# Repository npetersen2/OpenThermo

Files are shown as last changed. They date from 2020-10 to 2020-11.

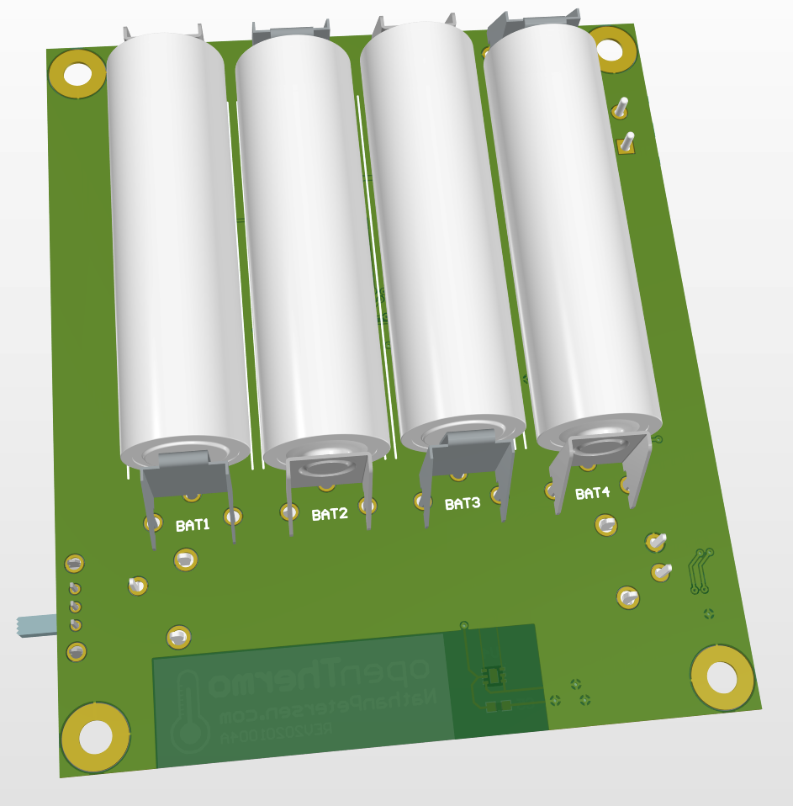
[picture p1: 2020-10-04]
hardware/REV20201004A/PCB_3D_bottom.png

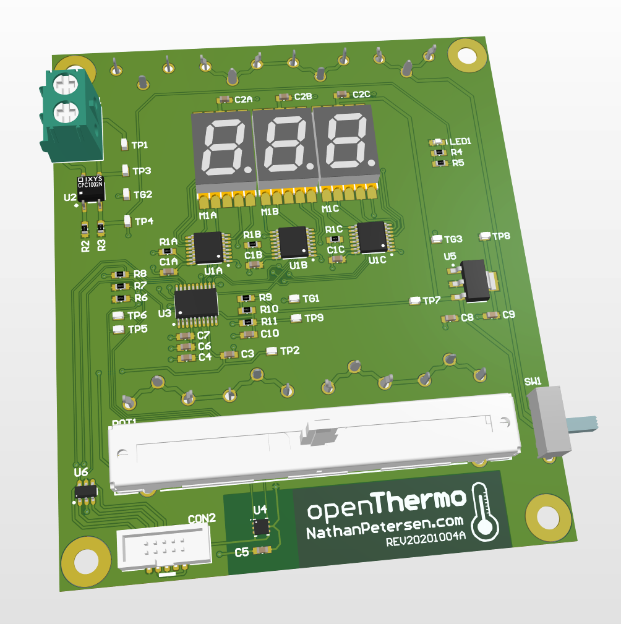
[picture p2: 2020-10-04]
hardware/REV20201004A/PCB_3D_top.png

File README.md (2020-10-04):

# openThermo

*Open-source thermostat for control of simple on/off furnaces.*

## About

This project was born after renting an old house with a crappy furnace controller. The crappy controller in the house used a timer to control when the heat was on; there was no closed-loop feedback to regulate temperature.

This project solves the issue by adding closed-loop temperature feedback.

## Contact

For questions or comments, please connect Nathan Petersen <nathan.petersen@wisc.edu>

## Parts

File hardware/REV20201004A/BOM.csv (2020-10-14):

Comment | Designator | Quantity | Qty 10 | Supplier Part Number 1
AA Holder | BAT1, BAT2, BAT3, BAT4 | 4 | 40 | 36-590-ND
AA Holder | BAT1, BAT2, BAT3, BAT4 | 4 | 40 | 36-596-ND
Capacitor | C1A, C1B, C1C, C2A, C2B, C2C, C4, C5, C6, C10 | 10 | 100 | 311-1343-1-ND
Capacitor | C3, C7, C8, C9 | 4 | 40 | 1276-1192-1-ND
ScrewTerminal_1x2 | CON1 | 1 | 10 | 277-1667-ND
20021521-00010D4LF | CON2 | 1 | 10 | 609-6533-ND
RED | LED1 | 1 | 10 | 160-1447-6-ND
VDMR10A0 | M1A, M1B, M1C | 3 | 30 | VDMR10A0CT-ND
PTA4543-2010CIB103 | POT1 | 1 | 10 | PTA4543-2010CIB103-ND
Resistor | R1A, R1B, R1C, R6, R7 | 5 | 50 | YAG1304CT-ND
Resistor | R2 | 1 | 10 | 311-470HRCT-ND
Resistor | R3, R8, R9, R10, R11 | 5 | 50 | 311-10.0KHRCT-ND
Resistor | R4, R5 | 2 | 20 | 311-1.00KHRCT-ND
EG1213 | SW1 | 1 | 10 | EG1906-ND
RCU-0C | TG1, TG2, TG3, TP1, TP2, TP3, TP4, TP5, TP6, TP7, TP8, TP9 | 12 | 120 | A106145CT-ND
STP08DP05TTR | U1A, U1B, U1C | 3 | 30 | 497-6029-1-ND
CPC1002NTR | U2 | 1 | 10 | CLA230CT-ND
STM32G030F6P6 | U3 | 1 | 10 | 497-STM32G030F6P6-ND
TMP117MAIDRVR | U4 | 1 | 10 | 296-51835-1-ND
AP2114H-3.3TRG1 | U5 | 1 | 10 | AP2114H-3.3TRG1DICT-ND
NUP4114HMR6T1G | U6 | 1 | 10 | NUP4114HMR6T1GOSCT-ND

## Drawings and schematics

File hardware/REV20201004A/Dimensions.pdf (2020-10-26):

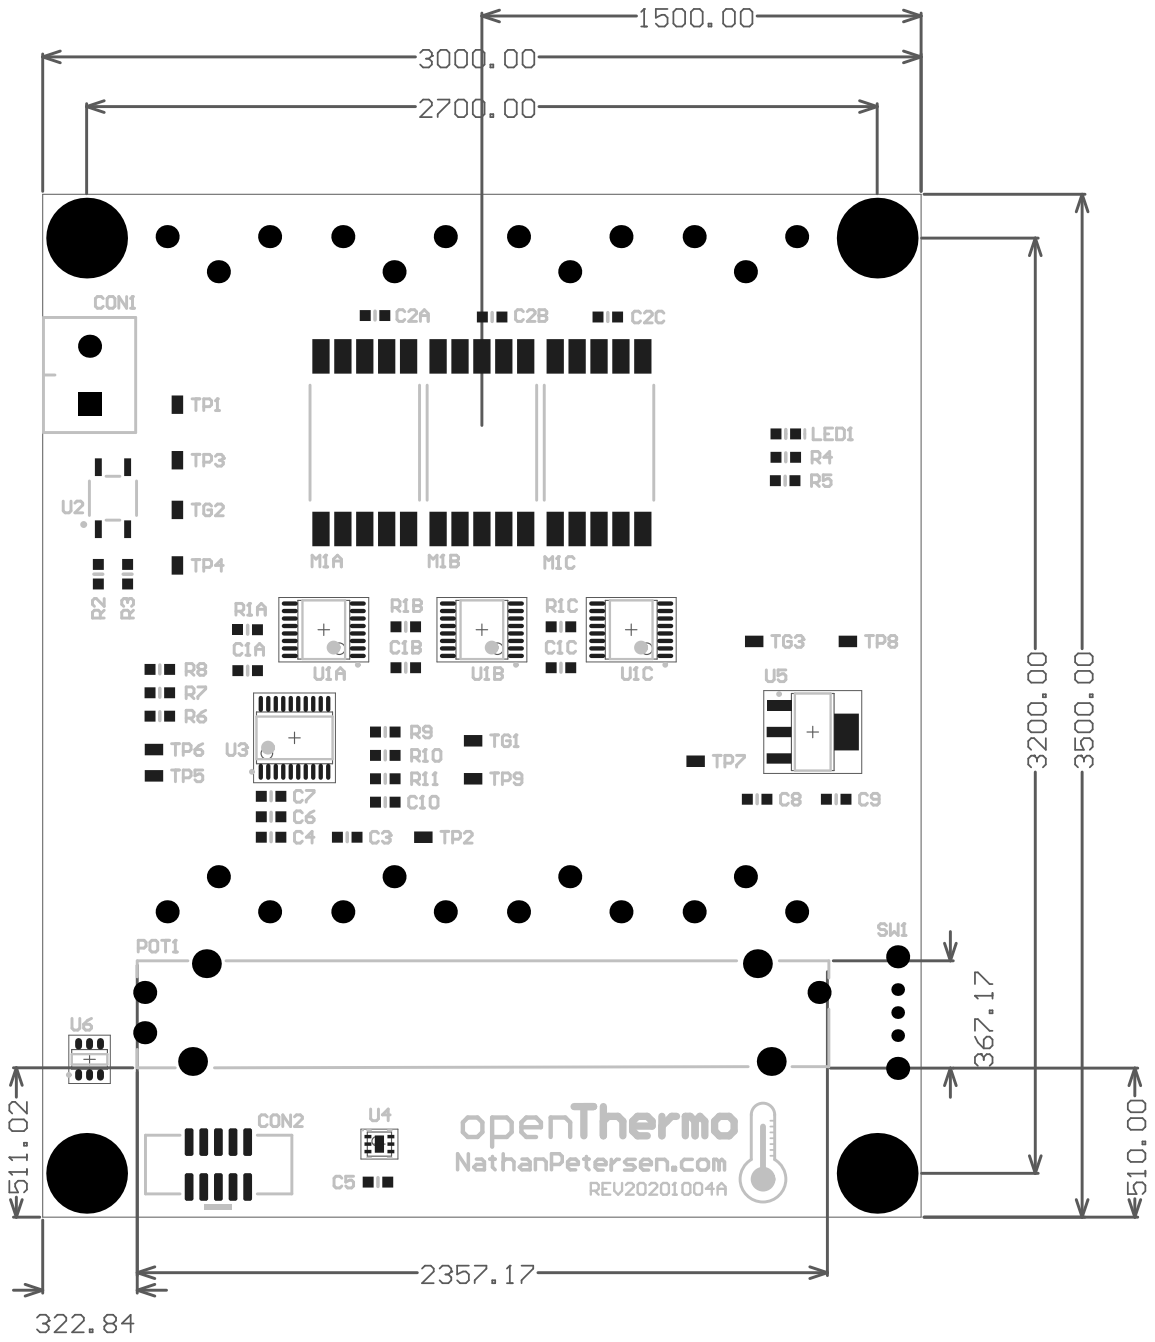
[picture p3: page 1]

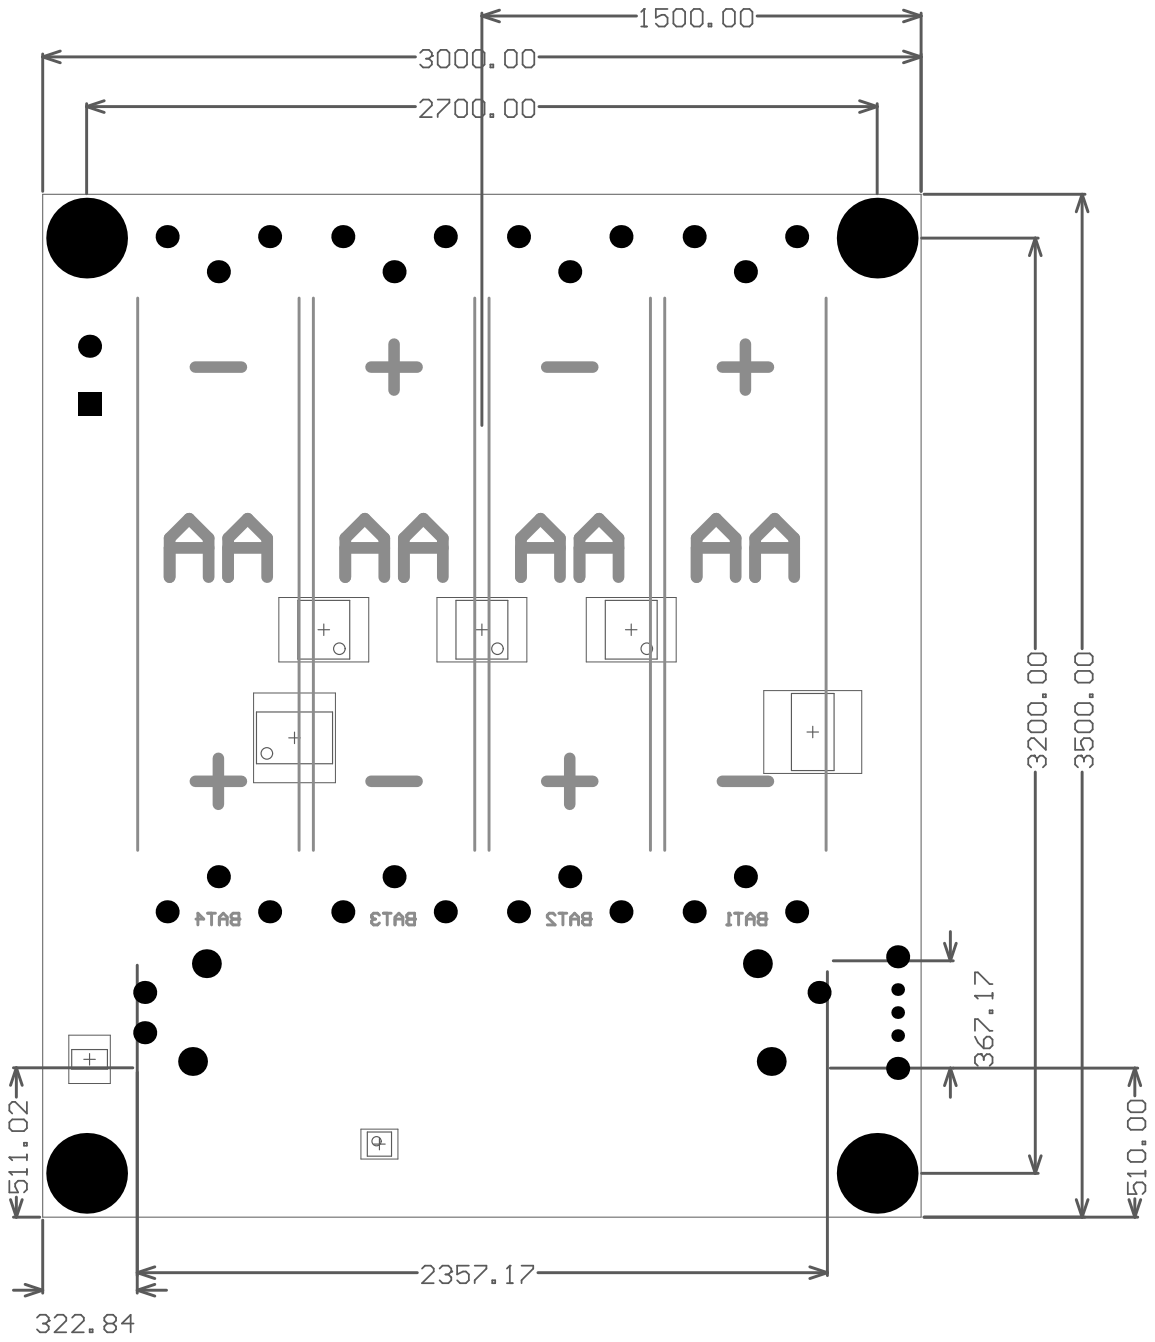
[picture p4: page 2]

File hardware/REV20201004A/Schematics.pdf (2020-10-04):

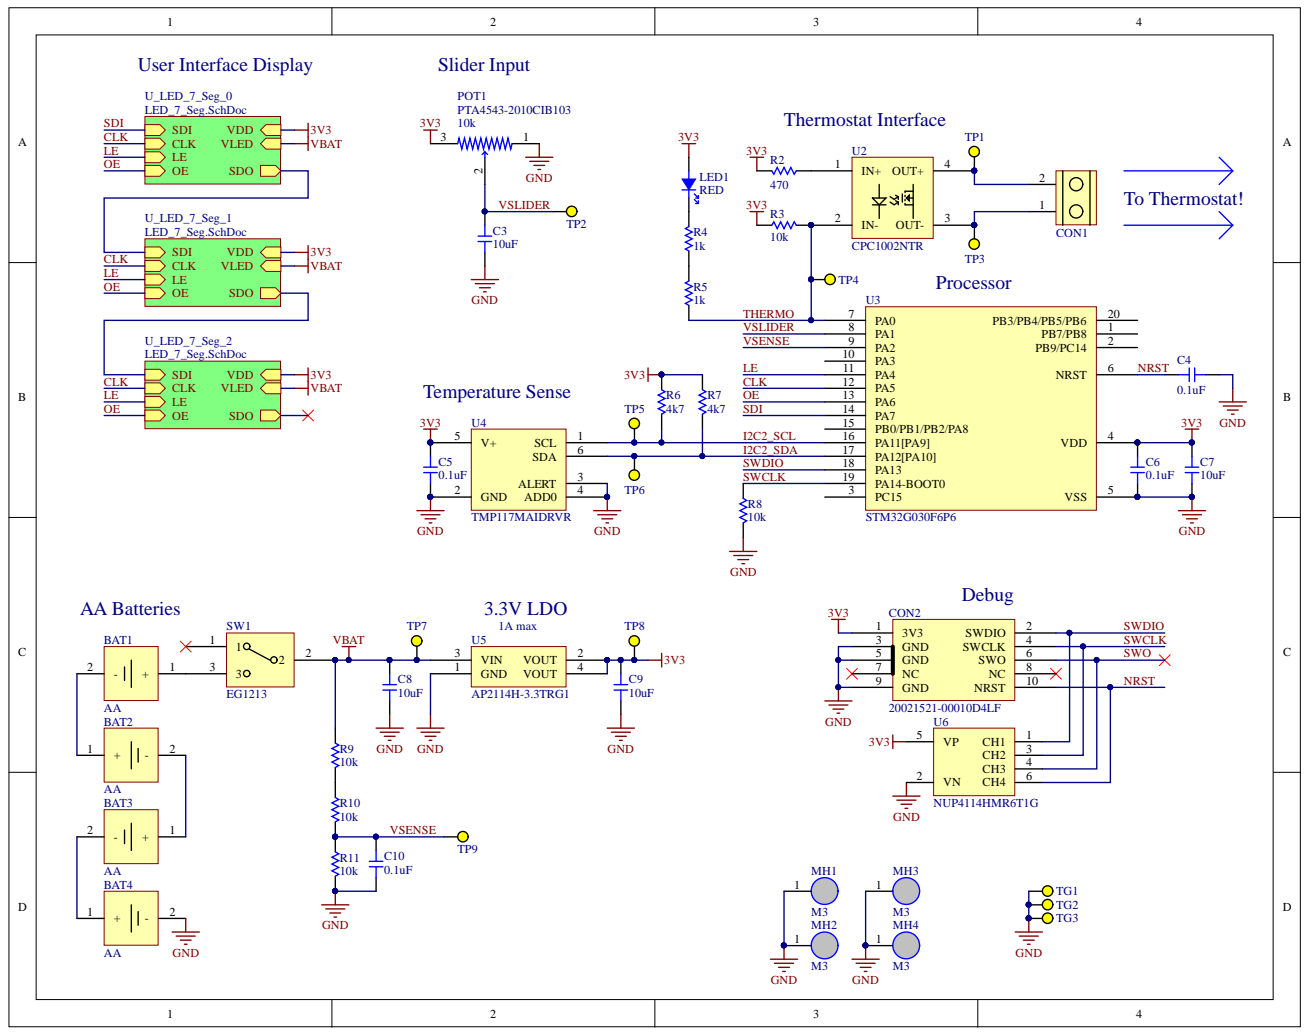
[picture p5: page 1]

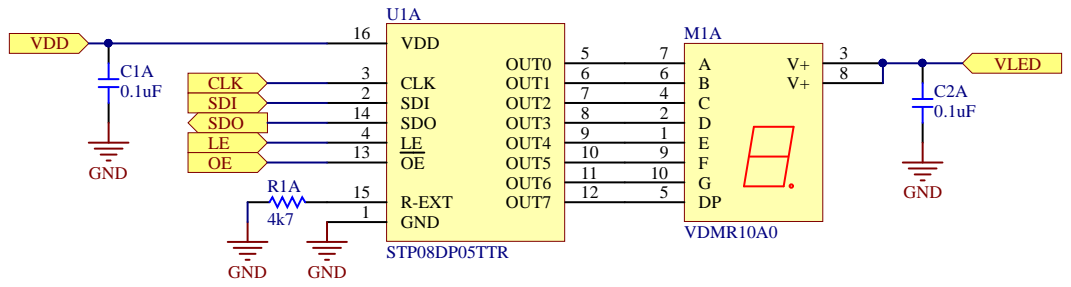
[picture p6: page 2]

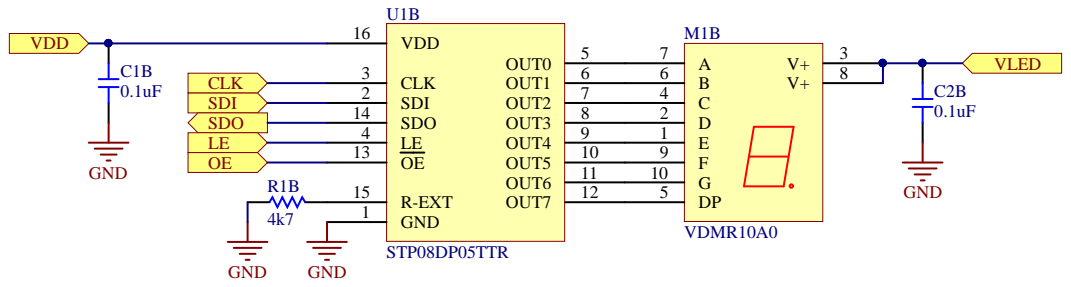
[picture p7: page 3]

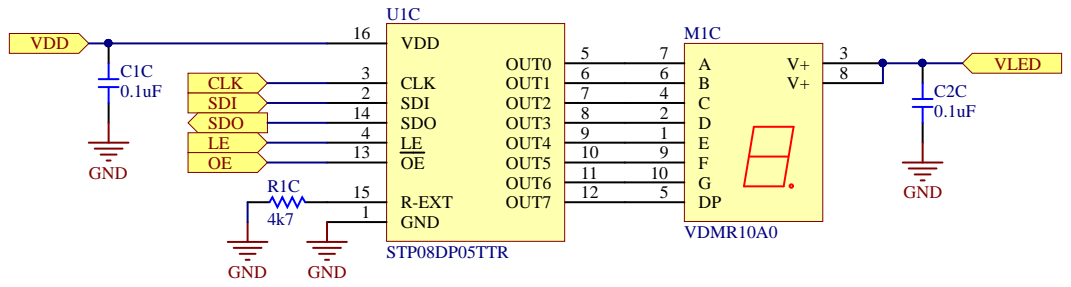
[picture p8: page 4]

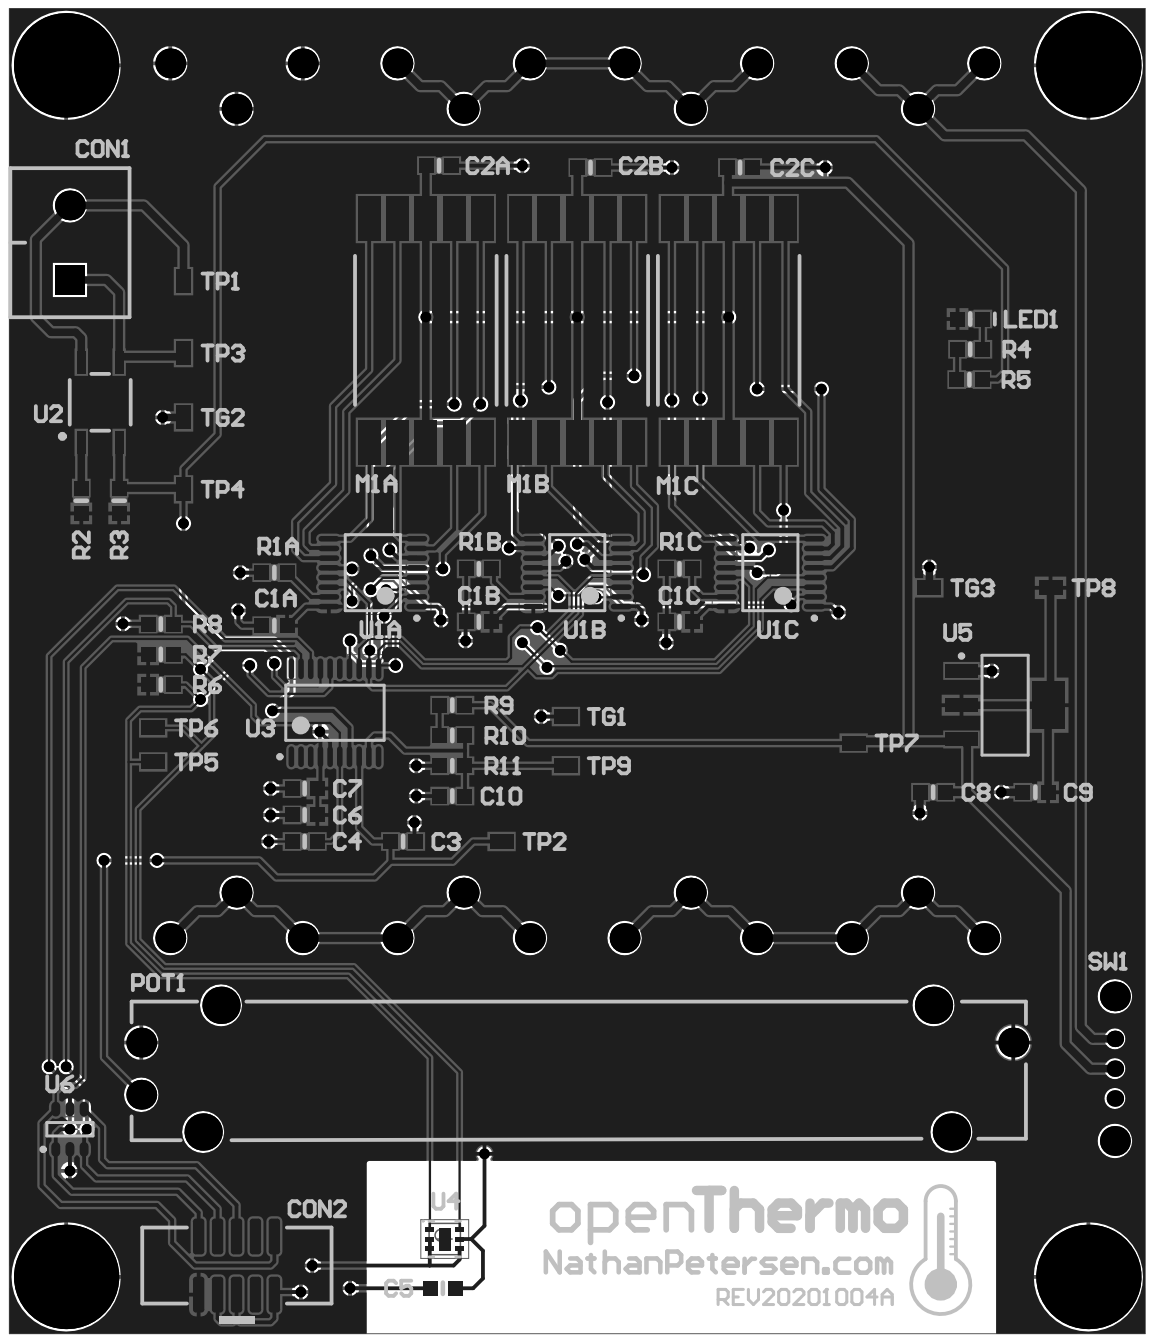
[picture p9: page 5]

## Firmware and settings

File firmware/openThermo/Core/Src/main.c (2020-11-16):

#include "platform.h"
#include "defines.h"
#include "app.h"
#include "led7seg.h"
#include "ui.h"
#include "drv_adc.h"
#include "drv_i2c.h"
#include "drv_spi.h"
#include "drv_tmp117.h"
#include <stdbool.h>

TIM_HandleTypeDef htim17;
TIM_HandleTypeDef htim3;

void SystemClock_Config(void);
static void MX_GPIO_Init(void);
static void MX_TIM17_Init(void);
static void MX_TIM3_Init(void);

int main(void)
{
  // Reset of all peripherals, Initializes the Flash interface and the Systick.
  HAL_Init();

  // Configure the system clock
  SystemClock_Config();

  // Initialize all configured peripherals
  drv_i2c_init();
  drv_adc_init();
  drv_spi_init();

  MX_GPIO_Init();
  MX_TIM17_Init();
  MX_TIM3_Init();

  drv_tmp117_init();

  ui_welcome_screen();

  // Wait for sensor to initialize
  HAL_Delay(2000);

  // Start timer!
  HAL_TIM_Base_Start_IT(&htim17);

  // Turn on Sleep on Exit. This feature puts the processor
  // to sleep after it services an ISR. Since this whole
  // application is ISR-based, this is perfect!
  HAL_PWR_EnableSleepOnExit();

  // Infinite loop
  //
  // The processor will only run this loop for a short amount of time
  // when first booted. Then, the SLEEPONEXIT feature will just put the processor
  // to sleep after the ISR!
  //
  while (1) {
	  asm("nop");
  }
}

// ALL WORK GOES HERE!
//
// This is called every 1 sec in ISR context
//
void HAL_TIM_PeriodElapsedCallback(TIM_HandleTypeDef* htim)
{
	app_callback();
}






/**
  * @brief System Clock Configuration
  * @retval None
  */
void SystemClock_Config(void)
{
  RCC_OscInitTypeDef RCC_OscInitStruct = {0};
  RCC_ClkInitTypeDef RCC_ClkInitStruct = {0};
  RCC_PeriphCLKInitTypeDef PeriphClkInit = {0};

  // Configure the main internal regulator output voltage
  HAL_PWREx_ControlVoltageScaling(PWR_REGULATOR_VOLTAGE_SCALE1);

  // Initializes the CPU, AHB and APB busses clocks
  RCC_OscInitStruct.OscillatorType = RCC_OSCILLATORTYPE_HSI;
  RCC_OscInitStruct.HSIState = RCC_HSI_ON;
  RCC_OscInitStruct.HSIDiv = RCC_HSI_DIV1;
  RCC_OscInitStruct.HSICalibrationValue = RCC_HSICALIBRATION_DEFAULT;
  RCC_OscInitStruct.PLL.PLLState = RCC_PLL_NONE;
  if (HAL_RCC_OscConfig(&RCC_OscInitStruct) != HAL_OK) {
	  PANIC;
  }

  // Initializes the CPU, AHB and APB busses clocks
  RCC_ClkInitStruct.ClockType = RCC_CLOCKTYPE_HCLK|RCC_CLOCKTYPE_SYSCLK
                              |RCC_CLOCKTYPE_PCLK1;
  RCC_ClkInitStruct.SYSCLKSource = RCC_SYSCLKSOURCE_HSI;
  RCC_ClkInitStruct.AHBCLKDivider = RCC_SYSCLK_DIV1;
  RCC_ClkInitStruct.APB1CLKDivider = RCC_HCLK_DIV1;

  if (HAL_RCC_ClockConfig(&RCC_ClkInitStruct, FLASH_LATENCY_0) != HAL_OK) {
	  PANIC;
  }

  // Initializes the peripherals clocks
  PeriphClkInit.PeriphClockSelection = RCC_PERIPHCLK_ADC;
  PeriphClkInit.AdcClockSelection = RCC_ADCCLKSOURCE_SYSCLK;
  if (HAL_RCCEx_PeriphCLKConfig(&PeriphClkInit) != HAL_OK) {
	  PANIC;
  }
}

/**
  * @brief TIM3 Initialization Function
  * @param None
  * @retval None
  */
static void MX_TIM3_Init(void)
{
  TIM_MasterConfigTypeDef sMasterConfig = {0};
  TIM_OC_InitTypeDef sConfigOC = {0};

  htim3.Instance = TIM3;
  htim3.Init.Prescaler = 0;
  htim3.Init.CounterMode = TIM_COUNTERMODE_UP;
  htim3.Init.Period = 10000;
  htim3.Init.ClockDivision = TIM_CLOCKDIVISION_DIV1;
  htim3.Init.AutoReloadPreload = TIM_AUTORELOAD_PRELOAD_ENABLE;

  if (HAL_TIM_PWM_Init(&htim3) != HAL_OK) {
    PANIC;
  }

  sMasterConfig.MasterOutputTrigger = TIM_TRGO_RESET;
  sMasterConfig.MasterSlaveMode = TIM_MASTERSLAVEMODE_DISABLE;
  if (HAL_TIMEx_MasterConfigSynchronization(&htim3, &sMasterConfig) != HAL_OK) {
    PANIC;
  }

  sConfigOC.OCMode = TIM_OCMODE_PWM1;
  sConfigOC.Pulse = 10000;
  sConfigOC.OCPolarity = TIM_OCPOLARITY_LOW;
  sConfigOC.OCFastMode = TIM_OCFAST_DISABLE;
  if (HAL_TIM_PWM_ConfigChannel(&htim3, &sConfigOC, TIM_CHANNEL_1) != HAL_OK) {
    PANIC;
  }

  // Start PWM outputs!
  HAL_TIM_PWM_Start(&htim3, TIM_CHANNEL_1);

}

/**
  * @brief TIM17 Initialization Function
  * @param None
  * @retval None
  */
static void MX_TIM17_Init(void)
{
  htim17.Instance = TIM17;
  htim17.Init.Prescaler = 40000;
  htim17.Init.CounterMode = TIM_COUNTERMODE_UP;
  htim17.Init.Period = 4; // 400 is every second
  htim17.Init.ClockDivision = TIM_CLOCKDIVISION_DIV1;
  htim17.Init.RepetitionCounter = 0;
  htim17.Init.AutoReloadPreload = TIM_AUTORELOAD_PRELOAD_ENABLE;
  if (HAL_TIM_Base_Init(&htim17) != HAL_OK) {
	  PANIC;
  }
}

/**
  * @brief GPIO Initialization Function
  * @param None
  * @retval None
  */
static void MX_GPIO_Init(void)
{
  GPIO_InitTypeDef GPIO_InitStruct = {0};

  /* GPIO Ports Clock Enable */
  __HAL_RCC_GPIOA_CLK_ENABLE();

  /*Configure GPIO pin Output Level */
  HAL_GPIO_WritePin(GPIOA, GPIO_PIN_0, GPIO_PIN_SET);
  HAL_GPIO_WritePin(GPIOA, GPIO_PIN_4, GPIO_PIN_RESET);
  HAL_GPIO_WritePin(GPIOA, GPIO_PIN_6, GPIO_PIN_SET);

  /*Configure GPIO pins : PA0 PA4 */
  GPIO_InitStruct.Pin = GPIO_PIN_0|GPIO_PIN_4;
  GPIO_InitStruct.Mode = GPIO_MODE_OUTPUT_PP;
  GPIO_InitStruct.Pull = GPIO_NOPULL;
  GPIO_InitStruct.Speed = GPIO_SPEED_FREQ_LOW;
  HAL_GPIO_Init(GPIOA, &GPIO_InitStruct);

  /*Configure GPIO pins : PA5 PA7 */
  GPIO_InitStruct.Pin = GPIO_PIN_5|GPIO_PIN_7;
  GPIO_InitStruct.Mode = GPIO_MODE_AF_PP;
  GPIO_InitStruct.Pull = GPIO_NOPULL;
  GPIO_InitStruct.Speed = GPIO_SPEED_FREQ_LOW;
  GPIO_InitStruct.Alternate = GPIO_AF0_SPI1;
  HAL_GPIO_Init(GPIOA, &GPIO_InitStruct);


  GPIO_InitStruct.Pin = GPIO_PIN_6;
  GPIO_InitStruct.Mode = GPIO_MODE_AF_PP;
  GPIO_InitStruct.Pull = GPIO_NOPULL;
  GPIO_InitStruct.Speed = GPIO_SPEED_FREQ_LOW;
  GPIO_InitStruct.Alternate = GPIO_AF1_TIM3;
  HAL_GPIO_Init(GPIOA, &GPIO_InitStruct);
}

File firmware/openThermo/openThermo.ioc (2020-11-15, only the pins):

Mcu.UserName=STM32G030F6Px
PA0.Signal=GPIO_Output
PA1.Signal=ADC1_IN1
PA13.Signal=SYS_SWDIO
PA14-BOOT0.Signal=SYS_SWCLK
PA2.Signal=ADC1_IN2
PA4.Signal=GPIO_Output
PA5.Signal=SPI1_SCK
PA6.Signal=S_TIM3_CH1
PA7.Signal=SPI1_MOSI

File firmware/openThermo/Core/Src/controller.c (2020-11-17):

#include "controller.h"
#include "ui.h"
#include "platform.h"
#include "drv_tmp117.h"
#include <stdint.h>
#include <stdbool.h>

// Tuning for LPF based on Ts = 1 sec
//
// Ts = 1
// A = exp(-2 * pi * Fb * Ts);
#define FILTER_A_4hour_TC (0.99956376286f)
inline static float __filter(float filter_gain_A, float input, float *prev_input);

static float heat_on_last_hour_percent_z1 = 0.0f;
static float heat_on_last_hour_percent = 0.0f;

static void __turn_off_heat(void);
static void __turn_on_heat(void);
static void __track_time(void);

static float tempF_ref = 55.0f; // Initialize to cold set point so heat doesn't start right away
static float tempF_deadband = 0.5f;

#define TIME_ON_MINIMUM  (2*60) // [sec]
#define TIME_OFF_MINIMUM (4*60) // [sec]

static uint32_t time_on_sec = 0;
static uint32_t time_off_sec = TIME_OFF_MINIMUM; // Initialize to having been off "forever"

static bool is_heat_on = false;

void controller_step(void)
{
	__track_time();

	float tempF_now = ui_get_latest_tempF();

	if (is_heat_on && tempF_now > (tempF_ref - tempF_deadband/2.0f)) {
		__turn_off_heat();
	}

	if (!is_heat_on && tempF_now < (tempF_ref - tempF_deadband)) {
		__turn_on_heat();
	}

	// Update filter for time heat has been on
	float on_percent = 0.0f;
	if (is_heat_on) {
		on_percent = 100.0f;
	}
	heat_on_last_hour_percent = __filter(FILTER_A_4hour_TC, on_percent, &heat_on_last_hour_percent_z1);
}

void controller_set_reference(float tempF)
{
	tempF_ref = tempF;
}

float controller_get_percent_heat_on_last_hour(void)
{
	return heat_on_last_hour_percent;
}

static void __turn_off_heat(void)
{
	if (!is_heat_on) {
		return;
	}

	// Check is safe to turn off
	if (time_on_sec >= TIME_ON_MINIMUM) {
		HAL_GPIO_WritePin(GPIOA, GPIO_PIN_0, 1);
		is_heat_on = false;
	}
}

static void __turn_on_heat(void)
{
	if (is_heat_on) {
		return;
	}

	// Check is safe to turn off
	if (time_off_sec >= TIME_OFF_MINIMUM) {
		HAL_GPIO_WritePin(GPIOA, GPIO_PIN_0, 0);
		is_heat_on = true;
	}
}

static void __track_time(void)
{
	if (is_heat_on) {
		// Record time
		time_on_sec++;
		time_off_sec = 0;
	} else {
		// Record time
		time_off_sec++;
		time_on_sec = 0;
	}
}

inline static float __filter(float filter_gain_A, float input, float *z1)
{
    float output = (input * (1.0f - filter_gain_A)) + *z1;
    *z1 = output * filter_gain_A;
    return output;
}

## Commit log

2020-10-04 Initial commit of REV A design
    [BOM.csv, LED_7_Seg.SchDoc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]
2020-10-14 Fix part number for slider
    [BOM.csv, PCB_v1.PcbDoc, Schematic.SchDoc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]
2020-10-16 Add hardware and firmware subfolders
    [BOM.csv, LED_7_Seg.SchDoc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]
2020-10-26 Add assembly drawings + step file
    [PCB_v1.PcbDoc]
2020-11-16 Add another UI screen to display percent of time heat was on for the last hour
2020-11-16 Add LPF to heat on percentage with 30min time constant
2020-11-17 Update heat on filtering to just be LPF, not averaging from array
